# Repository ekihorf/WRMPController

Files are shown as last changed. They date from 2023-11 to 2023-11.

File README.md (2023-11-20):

# WMRPController

DIY soldering iron controller for Weller RT tips.

There are many projects of controllers for Weller tips, but most use a DC power supply and PWM power control. This one uses AC power for the heating element. The power is controlled using zero-crossing switching, so EMI is reduced to a minimum.

I used a 3D printed handle for the RT tips, which can be found here: http://kair.us/projects/weller/diy_wmrp_handle/index.html.

This project is a playground for learning C++ on microcontrollers, so don't expect perfectly clean code ;).

### What is already implemented and works well
- AC control using triac with zero-crossing switching
- PID temperature controller
- User interface
- Storing settings in EEPROM
- Storing the last set temperature in EEPROM (uses wear levelling)
- Standby and auto power off

### What needs to be improved
- Temperature measurement. There is a small glitch (drop) in temperature every ~15 seconds

### What is NOT going to be implemented
- Cold junction compensation of the thermocouple. This device is for hobby use only and small difference in the tip temperature is not really a problem. Adding this feature would require additional wire and a temperature sensor, which would make the cable for the handle less flexible.

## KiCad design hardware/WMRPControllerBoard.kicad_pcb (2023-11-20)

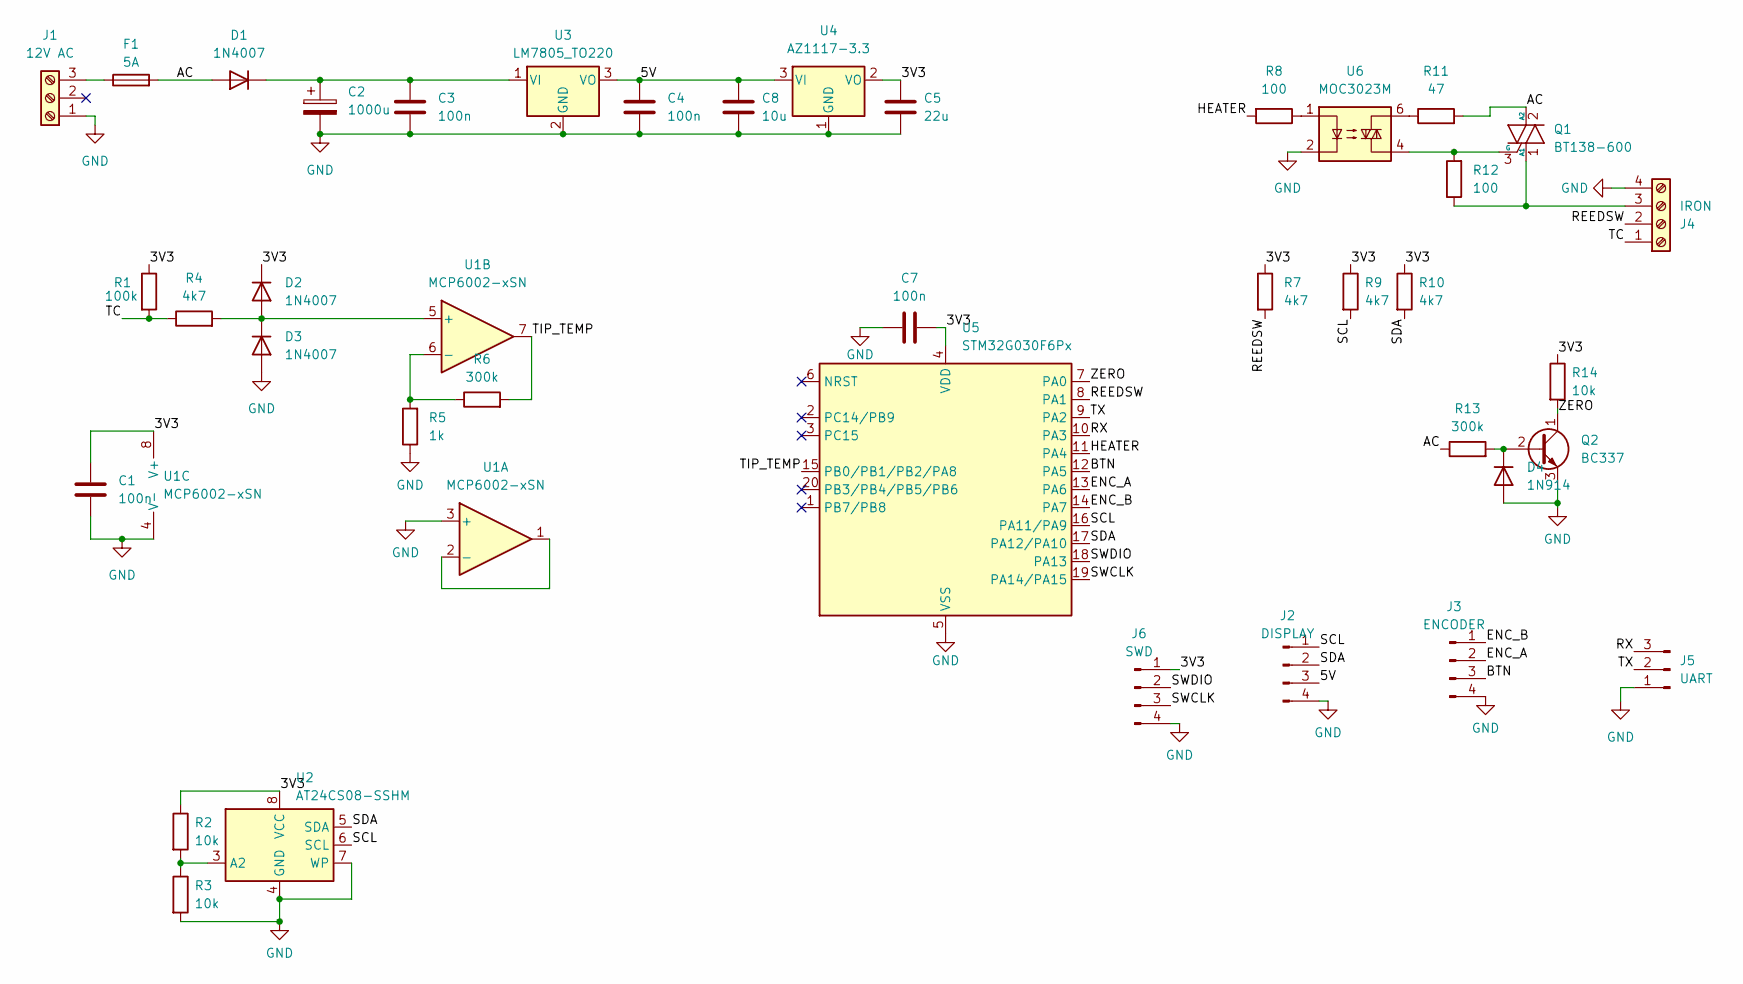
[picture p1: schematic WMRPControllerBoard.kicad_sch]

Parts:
C1, C3, C4, C7: 100n; C_0805_2012Metric_Pad1.18x1.45mm_HandSolder
C2: 1000u; CP_Radial_D13.0mm_P5.00mm
C5: 22u; C_1206_3216Metric_Pad1.33x1.80mm_HandSolder
C8: 10u; C_1206_3216Metric_Pad1.33x1.80mm_HandSolder
D1, D2, D3: 1N4007; D_DO-41_SOD81_P10.16mm_Horizontal
D4: 1N914; D_DO-35_SOD27_P7.62mm_Horizontal
F1: 5A; Fuseholder_Clip-5x20mm_Littelfuse_111_Inline_P20.00x5.00mm_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
J1: 12V AC; TerminalBlock_RND_205-00013_1x03_P5.00mm_Horizontal
J2: DISPLAY; PinHeader_1x04_P2.54mm_Vertical
J3: ENCODER; PinHeader_1x04_P2.54mm_Vertical
J4: IRON; TerminalBlock_RND_205-00014_1x04_P5.00mm_Horizontal
J5: UART; PinHeader_1x03_P2.54mm_Vertical
J6: SWD; PinHeader_1x04_P2.54mm_Vertical
Q1: BT138-600; TO-220-3_Vertical
Q2: BC337; TO-92_Inline_Wide
R1: 100k; R_0805_2012Metric_Pad1.20x1.40mm_HandSolder
R2, R3: 10k; R_0805_2012Metric_Pad1.20x1.40mm_HandSolder
R4, R7, R9, R10: 4k7; R_Axial_DIN0207_L6.3mm_D2.5mm_P7.62mm_Horizontal
R5: 1k; R_0805_2012Metric_Pad1.20x1.40mm_HandSolder
R6, R13: 300k; R_0805_2012Metric_Pad1.20x1.40mm_HandSolder
R8: 100; R_Axial_DIN0207_L6.3mm_D2.5mm_P7.62mm_Horizontal
R11: 47; R_0805_2012Metric_Pad1.20x1.40mm_HandSolder
R12: 100; R_0805_2012Metric_Pad1.20x1.40mm_HandSolder
R14: 10k; R_Axial_DIN0207_L6.3mm_D2.5mm_P7.62mm_Horizontal
U1: MCP6002-xSN; SOIC-8_3.9x4.9mm_P1.27mm
U2: AT24CS08-SSHM; SOIC-8_3.9x4.9mm_P1.27mm
U3: LM7805_TO220; TO-220-3_Vertical
U4: AZ1117-3.3; SOT-89-3_Handsoldering
U5: STM32G030F6Px; TSSOP-20_4.4x6.5mm_P0.65mm
U6: MOC3023M; SMDIP-6_W9.53mm

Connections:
/3V3: C1.1, C5.1, C7.2, D2.1 (K), J6.1, R1.1, R2.1, R7.1, R9.1, R10.1, R14.1, U1.8 (V+), U2.8 (VCC), U4.2 (VO), U5.4 (VDD)
/5V: C4.1, C8.1, J2.3, U3.3 (VO), U4.3 (VI)
/AC: D1.2 (A), F1.2, Q1.2 (A2), R11.2, R13.1
/BTN: J3.3, U5.12 (PA5)
/ENC_A: J3.2, U5.13 (PA6)
/ENC_B: J3.1, U5.14 (PA7)
/HEATER: R8.2, U5.11 (PA4)
/REEDSW: J4.2, R7.2, U5.8 (PA1)
/RX: J5.3, U5.10 (PA3)
/SCL: J2.1, R9.2, U2.6 (SCL), U5.16 (PA11/PA9)
/SDA: J2.2, R10.2, U2.5 (SDA), U5.17 (PA12/PA10)
/SWCLK: J6.3, U5.19 (PA14/PA15)
/SWDIO: J6.2, U5.18 (PA13)
/TC: J4.1, R1.2, R4.1
/TIP_TEMP: R6.2, U1.7, U5.15 (PB0/PB1/PB2/PA8)
/TX: J5.2, U5.9 (PA2)
/ZERO: Q2.1 (C), R14.2, U5.7 (PA0)
GND: C1.2, C2.2, C3.2, C4.2, C5.2, C7.1, C8.2, D3.2 (A), D4.2 (A), J1.1, J2.4, J3.4, J4.4, J5.1, J6.4, Q2.3 (E), R3.2, R5.1, U1.3 (+), U1.4 (V-), U2.4 (GND), U2.7 (WP), U3.2 (GND), U4.1 (GND), U5.5 (VSS), U6.2
unnamed: C2.1, C3.1, D1.1 (K), U3.1 (VI)
unnamed: D2.2 (A), D3.1 (K), R4.2, U1.5 (+)
unnamed: D4.1 (K), Q2.2 (B), R13.2
unnamed: F1.1, J1.3
unnamed: J4.3, Q1.1 (A1), R12.1
unnamed: Q1.3 (G), R12.2, U6.4
unnamed: R8.1, U6.1
unnamed: R11.1, U6.6
unnamed: U1.1, U1.2 (-)
unnamed: R5.2, R6.1, U1.6 (-)
unnamed: R2.2, R3.1, U2.3 (A2)

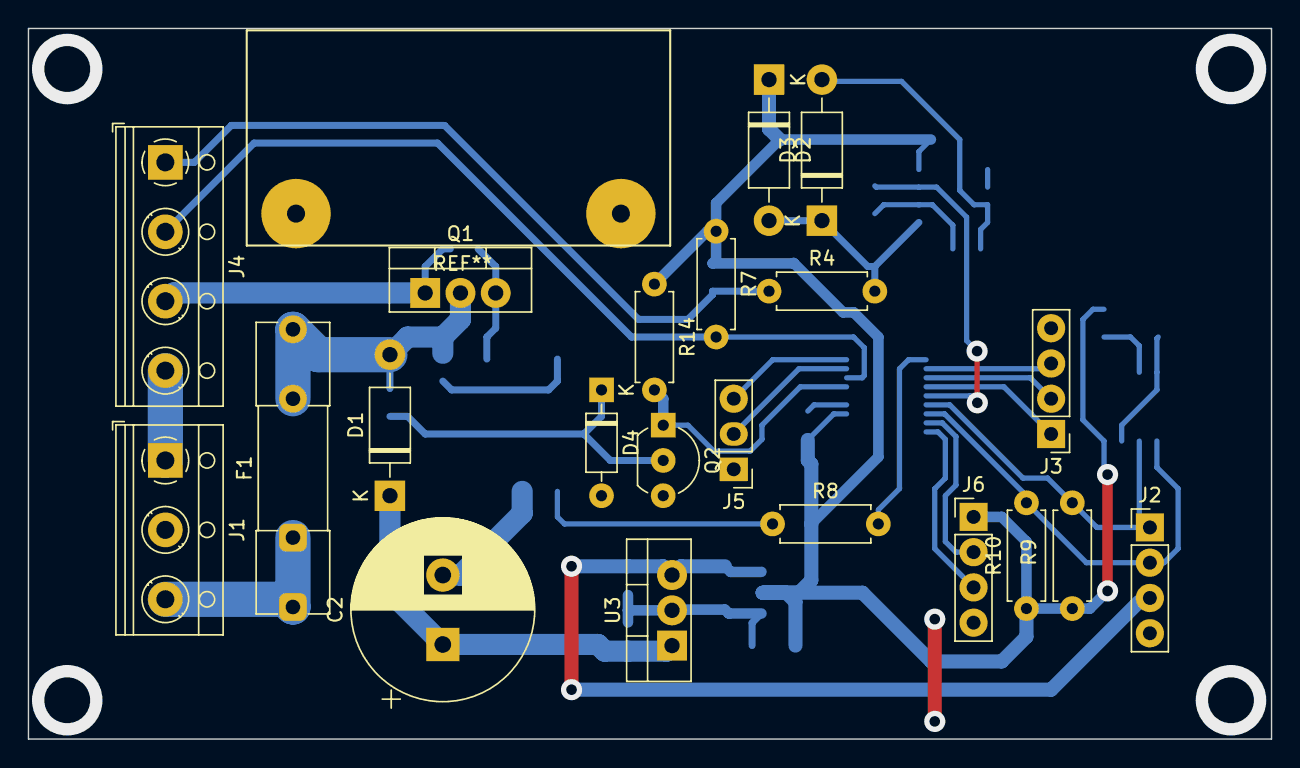
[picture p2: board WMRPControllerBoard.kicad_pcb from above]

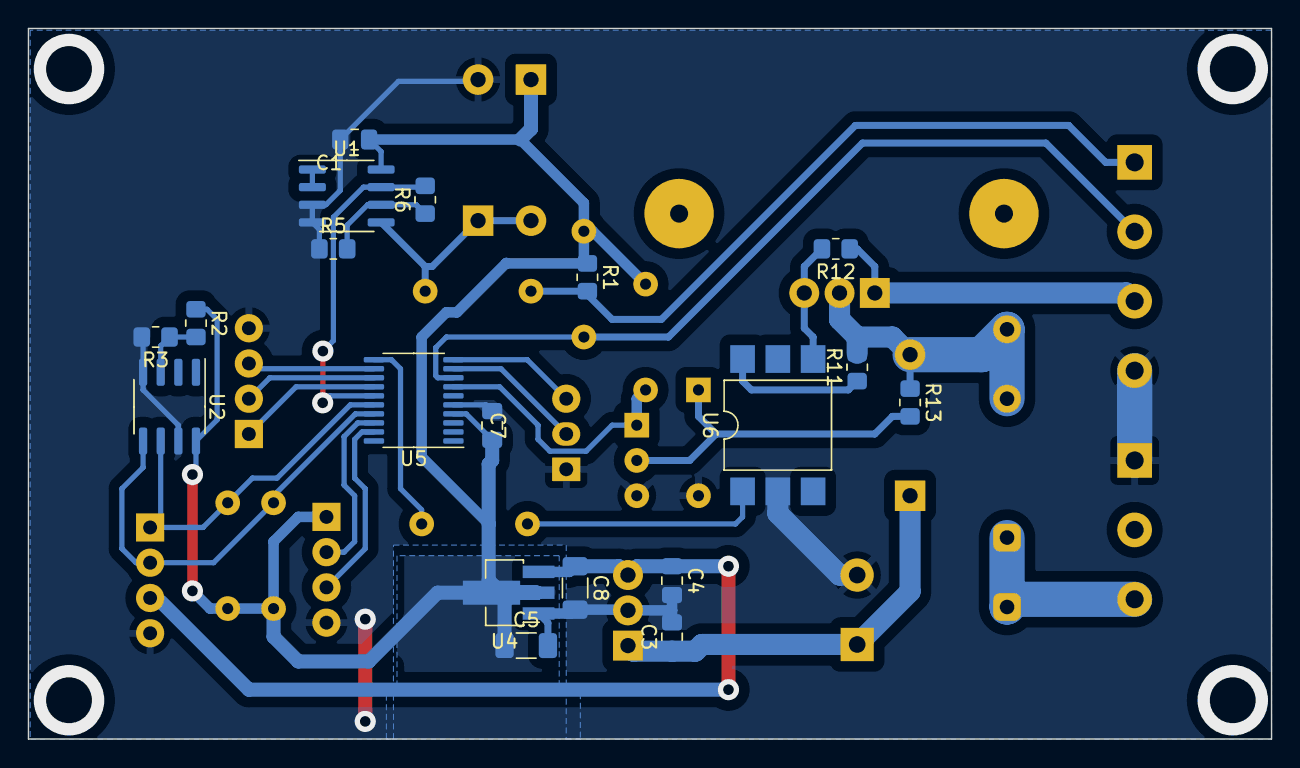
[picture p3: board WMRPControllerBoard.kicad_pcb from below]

Board: 2 copper layers, 89.5 x 51.2 mm, 40 parts (19 on the bottom side), 29 nets.

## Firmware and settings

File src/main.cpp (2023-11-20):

#include <libopencm3/stm32/rcc.h>
#include <libopencm3/cm3/nvic.h>
#include <libopencm3/cm3/systick.h>
#include <libopencm3/stm32/iwdg.h>
#include "BoardConfig.h"
#include "Scheduler.h"
#include "Pid.h"
#include "Utils.h"
#include "InterruptHandler.h"
#include "Ui.h"
#include "DeviceState.h"
#include "Constants.h"

struct Context {
	Pid& pid;
	AcControl& heater;
	TempSensor& temp_sensor;
	Encoder& encoder;
	Button& button;
	CharDisplay& display;
	Debug& debug;
	ui::Ui& ui;
	DeviceState& state;
	Nvs& nvs;
	StandbySensor& standby_sensor;
};

static void enablePeripherals()
{
	rcc_periph_clock_enable(RCC_GPIOA);
	rcc_periph_clock_enable(RCC_TIM14);
	rcc_periph_clock_enable(RCC_TIM16);
	rcc_periph_clock_enable(RCC_TIM3);
	rcc_periph_clock_enable(RCC_CRC);
	nvic_enable_irq(NVIC_EXTI0_1_IRQ);

	rcc_periph_clock_enable(RCC_I2C2);
	rcc_periph_clock_enable(RCC_DMA1);
	nvic_enable_irq(NVIC_DMA1_CHANNEL1_IRQ);

	rcc_periph_clock_enable(RCC_USART2);
}

static void controlTaskFunc(void* data) {
	auto& d = *static_cast<Context*>(data);

	d.heater.turnOff();
	iwdg_reset();

	switch (d.standby_sensor.update()) {
	case StandbySensor::State::Active:
		d.state.heating_status = HeatingStatus::On;
		break;
	case StandbySensor::State::Standby:
		d.state.heating_status = HeatingStatus::Standby;
		break;
	case StandbySensor::State::Off:
		d.state.heating_status = HeatingStatus::Off;
		break;
	}
	d.state.handle_in_stand = d.standby_sensor.isHandleInStand();

	time::Delay(200_us).wait();
	d.temp_sensor.performConversion();
	d.state.tip_temp = d.temp_sensor.getTemperature();
	Temperature temp = d.state.settings.standby_temp;
	if (d.state.heating_status == HeatingStatus::On) {
		temp = d.state.set_temp;
	}
	d.state.heater_power = d.pid.calculate(d.state.tip_temp.asDegreesC(), temp.asDegreesC());

	if (d.state.tip_temp > MAX_TIP_TEMP) {
		d.heater.turnOff();
		return;
	}

	if (d.state.heating_status != HeatingStatus::Off) {
		d.heater.turnOn(d.state.heater_power / 5);
	}
}

static ui::Buffer ui_buf;

static void uiTaskFunc(void* data) {
	auto& d = *static_cast<Context*>(data);

	auto delta = d.encoder.getDelta();
	uint32_t n = abs(delta);
	auto event = delta < 0 ? ui::Event::EncoderCCW : ui::Event::EncoderCW;
	while (n--) {
		d.ui.handleEvent(event);
	}

	if (d.state.temp_updated) {
		if (d.nvs.writeSts(d.state.set_temp.asDegreesC())) {
			d.state.temp_updated = false;
		}
	} else if (d.state.settings_updated) {
		d.state.settings_updated = false;
		d.nvs.writeLts(&d.state.settings);
		d.pid.setTunings(d.state.settings.pid_kp, d.state.settings.pid_ki, d.state.settings.pid_kd);
		d.temp_sensor.setVref(d.state.settings.tc_vref);
		d.temp_sensor.setAmpGain(d.state.settings.tc_amp_gain);
		d.temp_sensor.setOffset(d.state.settings.tc_offset);
		d.standby_sensor.setDelays(d.state.settings.standby_delay, d.state.settings.off_delay);
	}
	
	d.ui.draw(ui_buf);

	d.display.goTo(0, 0);
	d.display.printN(ui_buf.line1, 16);
	d.display.goTo(1, 0);
	d.display.printN(ui_buf.line2, 16);
	
	d.display.flushBuffer();
}

static void btnTaskFunc(void* data) {
	auto& d = *static_cast<Context*>(data);

	auto event = d.button.update();

	if (event == Button::EventType::ShortPress) {
		if (d.ui.isAtMainView()) {
			d.standby_sensor.reset();
		}
		d.ui.handleEvent(ui::Event::ButtonShortPress);
	} else if (event == Button::EventType::LongPress) {
		d.ui.handleEvent(ui::Event::ButtonLongPress);
	}
}

static void debugTaskFunc(void* data) {
	auto& d = *static_cast<Context*>(data);

	Debug::Data debug_data {
		.tip_temp = static_cast<uint32_t>(d.state.tip_temp.asDegreesC()),
		.set_temp = static_cast<uint32_t>(d.state.set_temp.asDegreesC()),
		.power = d.state.heater_power
	};

	d.debug.sendData(debug_data);
}

static void printMsg(Context& ctx, const char* text) {
	ctx.display.goTo(0, 0);
	ctx.display.printNBlocking(text, 16);
}

static void loadSettings(Context& ctx) {
	bool result = ctx.nvs.readLts(&ctx.state.settings);
	if (result && !ctx.button.isPressedRaw()) {
		auto sts = ctx.nvs.readSts();
		if (sts.has_value()) {
			auto temp = Temperature(sts.value());
			if (temp <= MAX_TIP_TEMP && temp >= MIN_TIP_TEMP) {
				ctx.state.set_temp = temp;
			}
		}
		return;
	}

	printMsg(ctx, "EEPROM INIT...");
	time::Delay(200_ms).wait();

	result = ctx.nvs.erase();
	if (!result) {
		printMsg(ctx, "EEPROM ERROR 01");
		while (true)
			;
	}

	ctx.state.settings = defaults::SETTINGS;
	result = ctx.nvs.writeLts(&ctx.state.settings);
	if (!result) {
		printMsg(ctx, "EEPROM ERROR 02");
		while (true)
			;
	}

	printMsg(ctx, "EEPROM INIT OK");
	time::Delay(1_s).wait();
}

void registerDisplaySymbols(CharDisplay& display) {
	int count = sizeof(ui::SYMBOLS_DATA) / sizeof(ui::SYMBOLS_DATA[0]);
	for (int i = 0; i < count; ++i) {
		display.defineCharacter(i+1, ui::SYMBOLS_DATA[i]);
		display.flushBuffer();
		while(display.isBusBusy())
			;
	}
}

int main()
{
	rcc_clock_setup(&rcc_clock_config[RCC_CLOCK_CONFIG_HSI_16MHZ]);
	
	enablePeripherals();

	time::setup(time_config);

	I2cDma i2c(i2c_config);	
	// Wait for the display to initialize before sending commands
	time::Delay(50_ms).wait();
	CharDisplay display(i2c, disp_config);
	time::Delay(50_ms).wait();
	registerDisplaySymbols(display);

	AcControl heater(heater_config);
	Encoder encoder(encoder_config);
	TempSensor temp_sensor(temp_config);
	StandbySensor standby_sensor(standby_config);
	Nvs nvs(i2c, nvs_config);
	Debug debug(debug_config);
	Button button(button_config);

	Pid pid(CONTROL_PERIOD);
	pid.setLimits(0, MAX_HEATER_POWER);

	DeviceState device_state {
		// This will be overriden with the data from EEPROM later
		.set_temp = 200_degC,
		.tip_temp = 0_degC,
		.heater_power = 0,
		.heating_status = HeatingStatus::Off,
		.temp_updated = false,
		.settings_updated = false,
		.settings = defaults::SETTINGS,
		.handle_in_stand = false
	};

	ui::Ui main_ui(device_state);

	ui::Parameter param_temp_increment("Temp. increment", "\337C", device_state.settings.temp_increment.value, 5, 20, 5);
	ui::Parameter param_standby_temp("Standby temp.", "\337C", device_state.settings.standby_temp.value, 100, 250, 5);
	ui::Parameter param_standby_delay("Standby delay", "s", reinterpret_cast<int32_t&>(device_state.settings.standby_delay.value), 0, 600'000'000, 10'000'000, 6, false);
	ui::Parameter param_off_delay("Off delay", "s", reinterpret_cast<int32_t&>(device_state.settings.off_delay.value), 0, 600'000'000, 10'000'000, 6, false);
	ui::Parameter param_tc_vref("TC Vref", "mV", reinterpret_cast<int32_t&>(device_state.settings.tc_vref.value), 3200, 3400, 1);
	ui::Parameter param_tc_offset("TC offset", "\337C", device_state.settings.tc_offset.value, -100, 100, 1);
	ui::Parameter param_tc_amp_gain("TC amp gain", "", device_state.settings.tc_amp_gain, 250, 400, 1);
	ui::Parameter param_pid_kp("PID Kp", "", device_state.settings.pid_kp, 0, 10000, 10, 3);
	ui::Parameter param_pid_ki("PID Ki", "", device_state.settings.pid_ki, 0, 10000, 10, 3);
	ui::Parameter param_pid_kd("PID Kd", "", device_state.settings.pid_kd, 0, 10000, 10, 3);
	main_ui.addParameter(param_temp_increment);
	main_ui.addParameter(param_standby_temp);
	main_ui.addParameter(param_standby_delay);
	main_ui.addParameter(param_off_delay);
	main_ui.addParameter(param_tc_vref);
	main_ui.addParameter(param_tc_offset);
	main_ui.addParameter(param_tc_amp_gain);
	main_ui.addParameter(param_pid_kp);
	main_ui.addParameter(param_pid_ki);
	main_ui.addParameter(param_pid_kd);

	Context task_context {
		.pid = pid,
		.heater = heater,
		.temp_sensor = temp_sensor,
		.encoder = encoder,
		.button = button,
		.display = display,
		.debug = debug,
		.ui = main_ui,
		.state = device_state,
		.nvs = nvs,
		.standby_sensor = standby_sensor
	};

	// Make sure that the I2C transfer to the display finished
	time::Delay(50_ms).wait();
	loadSettings(task_context);

	pid.setTunings(device_state.settings.pid_kp, device_state.settings.pid_ki, device_state.settings.pid_kd);
	temp_sensor.setAmpGain(device_state.settings.tc_amp_gain);
	temp_sensor.setOffset(device_state.settings.tc_offset);
	temp_sensor.setVref(device_state.settings.tc_vref);
	standby_sensor.setDelays(device_state.settings.standby_delay, device_state.settings.off_delay);

	iwdg_set_period_ms(1500);
	iwdg_start();
	
	Task control_task(5_ms, CONTROL_PERIOD, controlTaskFunc);
	control_task.setData(&task_context);
	Task ui_task(5_ms, 100_ms, uiTaskFunc);
	ui_task.setData(&task_context);
	Task debug_task(5_ms, 200_ms, debugTaskFunc);
	debug_task.setData(&task_context);
	Task button_task(1_ms, 5_ms, btnTaskFunc);
	button_task.setData(&task_context);

	Scheduler scheduler;
	scheduler.addTask(ui_task);
	scheduler.addTask(control_task);
	scheduler.addTask(debug_task);
	scheduler.addTask(button_task);

	time::Delay(50_ms).wait();

	while (1) {
		scheduler.runNextTask();
	}

	return 0;
}

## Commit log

2023-11-20 Add ADC reading
2023-11-20 Add temperature conversion (type D thermocouple)
2023-11-20 Implement PID controller
2023-11-20 Implement display driver
2023-11-20 Implement abstraction layer for interrupt handlers
2023-11-20 Implement encoder handling
2023-11-20 Use DMA for I2C comm
2023-11-20 Select correct DMAREQ_ID for given I2C periph
2023-11-20 Add button library
2023-11-20 Add printN method to display driver
2023-11-20 Implement Short Term Storage
    [main.cpp]
2023-11-20 Refactor driver configurations
2023-11-20 Move configs to BoardConfig.h
2023-11-20 Change Pid interface
2023-11-20 Refactor driver interfaces
2023-11-20 Reset watchdog from control task
    [main.cpp]
2023-11-20 Fix pid controller
2023-11-20 Change pid defaults
2023-11-20 Add schematics and PCB
    [WMRPControllerBoard.kicad_pcb, WMRPControllerBoard.kicad_sch]
2023-11-20 Use error instead of input in PID derivative calculation
